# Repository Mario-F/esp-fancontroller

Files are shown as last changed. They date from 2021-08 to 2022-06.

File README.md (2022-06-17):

# Fan Controller

This is a simple project in development to provide a multi temperature sensor IoT device including a Fan Controller, the focus resides in providing a JSON HTTP interface for scrape and configure remotely.

A example schematic can be viewed [here](./schematic.pdf)

## State of the Project

The projects actual state is a working temperature fancontroller including metrics export in prometheus format.

Features:

* Control a fans speed by temp sensor of your choice
* Up to 8 temperature sensors
* Naming sensors
* Configuration is done over http
* Configuration is saved to flash memory and read on start
* Prometheus metrics export endpoint

Requriements:

* A compatible ESP8266 (i am using the  ESP-12E variant)
* DS18B20 Temparatur Sensors
* PWM Controlles FAN (4wire)

## Quickstart

Create a `src/Credentials.h` with your wifi credentials, use `src/Credentials.h.tpl`

On remote Host:

```shell
pio remote agent start
```

Connect Monitor:

```shell
pio remote device monitor -b 115200
```

Upload Filesystem:

```shell
pio remote run -t uploadfs --force-remote
```

Upload and Flash remote:

```shell
pio remote run -t upload --force-remote
```

## Configuration

Check http files at [http](./control/common.http)

## Test

To use the http calls provided by the `test/` folder you can use vscode extension `REST Client` and this config under `.vscode/settings.json`:

```json
{
  "rest-client.environmentVariables": {
    "$shared": {
        "fanControllerHost": "1.2.3.4"
    }
  }
}
```

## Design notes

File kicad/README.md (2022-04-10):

# ESP Fancontroller KiCAD

## Sources

* <https://github.com/Basirk/kicad-ESP8266>

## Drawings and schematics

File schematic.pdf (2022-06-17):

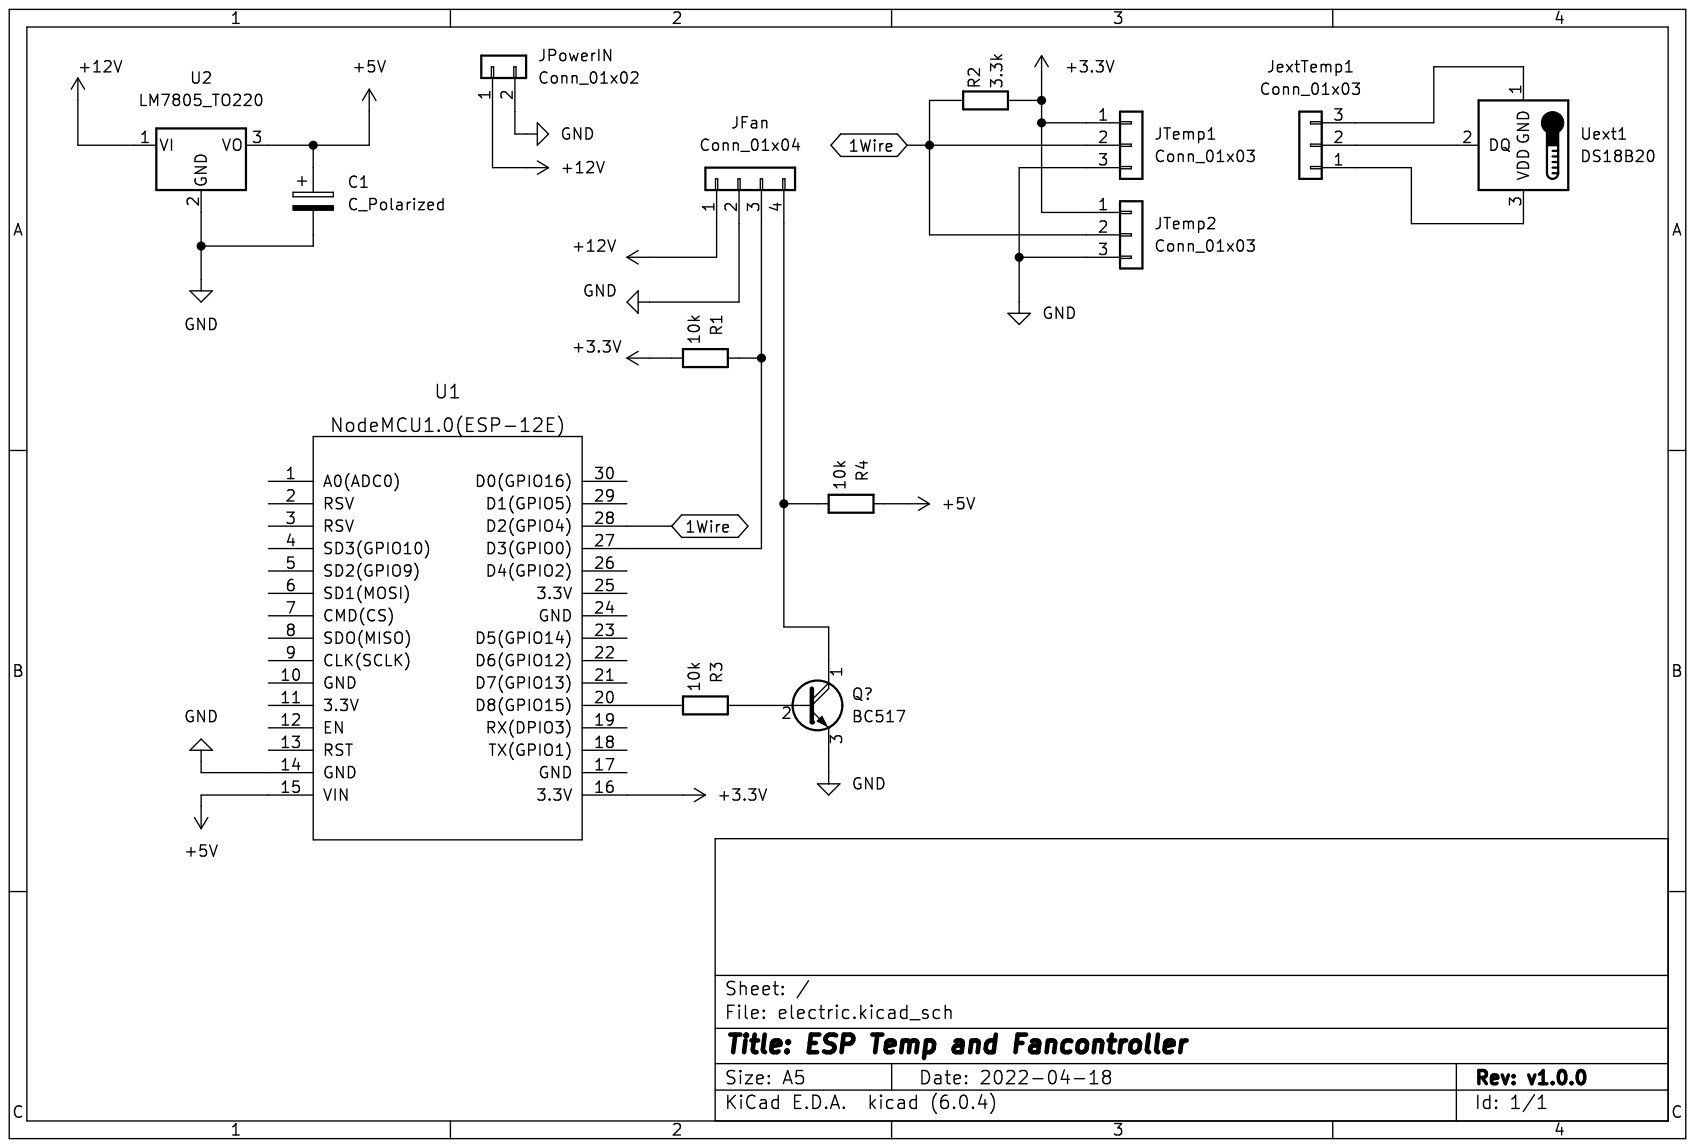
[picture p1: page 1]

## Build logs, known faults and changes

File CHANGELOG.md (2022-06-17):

## [1.0.1](https://github.com/Mario-F/esp-fancontroller/compare/v1.0.0...v1.0.1) (2022-06-17)

### Bug Fixes

* **kicad:** create updated schematic ([54e13bb](https://github.com/Mario-F/esp-fancontroller/commit/54e13bb4d6108e2599d8c90c35eac1526ac92437))

### Miscellaneous

* **kicad:** moved schematic to root level ([8c5dbdd](https://github.com/Mario-F/esp-fancontroller/commit/8c5dbddbb45d0ad8417b20ad893cc7ea08e1907a))

## 1.0.0 (2022-05-22)

### Features

* :art: added status output for wifi and chip data ([d69d1e6](https://github.com/Mario-F/esp-fancontroller/commit/d69d1e6ebad522e076c9f73d800b4b001d841ded))
* :art: moved fan functions to own controller class ([935127f](https://github.com/Mario-F/esp-fancontroller/commit/935127f24fae7acba9bc1cef40f75b0bdaf1629e))
* :rocket: progress on configuration manager ([7881e2b](https://github.com/Mario-F/esp-fancontroller/commit/7881e2be0a1dddb4992f8db848023550b6f6fbee))
* :tada: begin work on config manager ([cb3c988](https://github.com/Mario-F/esp-fancontroller/commit/cb3c9884f14cba346a7c8f8f8d19c752608c9d75))
* :white_check_mark: moved json responses to ArduinoJson ([25253c7](https://github.com/Mario-F/esp-fancontroller/commit/25253c721c5412c7e3ed9f4f043d014e6bdd787b))
* added basic metrics (prom) endpoint ([dabcb13](https://github.com/Mario-F/esp-fancontroller/commit/dabcb13324245bd66e729920437ce46721af684a))
* added endpoint to set target sensor ([8ea7231](https://github.com/Mario-F/esp-fancontroller/commit/8ea723110422440d83be419283e85b96e1561a98))
* added function to set target temp ([1a736ce](https://github.com/Mario-F/esp-fancontroller/commit/1a736ce7e426682b6dfc4689cf2a2b665bd8ac39))
* added http hint ([f69facf](https://github.com/Mario-F/esp-fancontroller/commit/f69facfd5607e1c8681c1aa31448a224536f92cd))
* added instance naming function ([1221135](https://github.com/Mario-F/esp-fancontroller/commit/1221135f71680052e9a6b277e079cc185640ef04))
* added littlefs config file ([a7b2257](https://github.com/Mario-F/esp-fancontroller/commit/a7b2257ad6ee99b8aeda5d129869e67d94719fc1))
* added MetricsManager ([a68700c](https://github.com/Mario-F/esp-fancontroller/commit/a68700c6439b438ca3a5afce557c4270e2bf40d3))
* added save and load for sensors config ([fbf5647](https://github.com/Mario-F/esp-fancontroller/commit/fbf5647b08fc36d793b7092a66f029a73809f410))
* added semantic-release ([df99ef0](https://github.com/Mario-F/esp-fancontroller/commit/df99ef027b271fb344b72f5a1609033454dce289))
* added state of development ([9d5edda](https://github.com/Mario-F/esp-fancontroller/commit/9d5edda11bf2e14335f78416197fb627b56b3011))
* **fan:** added invertable pwm ([f1688ce](https://github.com/Mario-F/esp-fancontroller/commit/f1688ce9424de60b3bc60a4ed3fafacaa6be249c))
* implement config save and default fanspeed ([dad6101](https://github.com/Mario-F/esp-fancontroller/commit/dad6101de81df73105e113d472e79db4e4fe74ba))
* implement initial fan temp regulation loop and min speed ([3d8098d](https://github.com/Mario-F/esp-fancontroller/commit/3d8098d8f54da745e140aee63d695d9587b85399))
* implement persistent sensor config names ([553c988](https://github.com/Mario-F/esp-fancontroller/commit/553c988b554092a35305f27facc4c0887cbb739a))
* **kicad:** added external esp8266 schema lib ([92a5456](https://github.com/Mario-F/esp-fancontroller/commit/92a54567cf7fb0318d002e41d7b1d69032f7264d))
* **kicad:** added fan output ([728274c](https://github.com/Mario-F/esp-fancontroller/commit/728274c60731fd144802d97b685053abbf6846fc))
* **kicad:** added folder with gitignore ([f87e762](https://github.com/Mario-F/esp-fancontroller/commit/f87e7622ff89ff17e8840cf7b009b8f1a9ee78b3))
* **kicad:** added initial schema ([83ac9ba](https://github.com/Mario-F/esp-fancontroller/commit/83ac9baa391b04ac0164315ea2143bda18726259))
* **kicad:** added inverted pwm with npn transistor ([26a1dd7](https://github.com/Mario-F/esp-fancontroller/commit/26a1dd7429f6dc3bcad4b86b78ffa68bf717dd3f))
* **kicad:** added main power connector ([cacbbb5](https://github.com/Mario-F/esp-fancontroller/commit/cacbbb5a536033471374252cbc72831ff4be9d0d))
* **kicad:** added power supply ([2212b71](https://github.com/Mario-F/esp-fancontroller/commit/2212b7137a7b87f6feb7ddc53b19c53b456bd0fa))
* **kicad:** added schmatic pdf ([f162809](https://github.com/Mario-F/esp-fancontroller/commit/f1628093d51be28d57f0f11621bcca81c8a14f14))
* **kicad:** added temp sensor circut ([7f1dbff](https://github.com/Mario-F/esp-fancontroller/commit/7f1dbffcfd1cf33a3d86ea3ccafdd922216403ff))
* **kicad:** tidy up shematic ([72aebfe](https://github.com/Mario-F/esp-fancontroller/commit/72aebfe30c0013fe253f4c1a0b26db9ac45b828e))
* **metrics:** added esp stats ([e9ab47f](https://github.com/Mario-F/esp-fancontroller/commit/e9ab47f6b84f04db90c6bfbd70e5b267e7e282d8))
* **metrics:** added local wlan ip ([800d655](https://github.com/Mario-F/esp-fancontroller/commit/800d655ff1cc420984c51e188afeb5541f20c143))
* **metrics:** added target temp for selected sensor ([236e972](https://github.com/Mario-F/esp-fancontroller/commit/236e972583302a9cf2b1a0c2e3bbf6722512e1d9))
* more intelligent fan temp step up process ([fc04ccf](https://github.com/Mario-F/esp-fancontroller/commit/fc04ccf337ee6d927e31baa42326d6ce63cb6d32))
* more prometheus metrics functions ([61698de](https://github.com/Mario-F/esp-fancontroller/commit/61698de40315ce0e4a8f76d6c17465308baedcc8))
* reduce sample rate for temp sensors ([611b1be](https://github.com/Mario-F/esp-fancontroller/commit/611b1be993f6deafc19d2a1083b04f86eb20d853))
* some cleanups and improvements ([0b6a78a](https://github.com/Mario-F/esp-fancontroller/commit/0b6a78a0fc1936c3c375fe1ce348cee30e22c3b4))
* update analogWrite to new range 0 to 255 ([175f3df](https://github.com/Mario-F/esp-fancontroller/commit/175f3dfab191ccee57bab3a42f32da30c6a343cb))
* use camel case for config json rep ([58247b5](https://github.com/Mario-F/esp-fancontroller/commit/58247b5ff6fd0d7be5a7e8624a9683cd8872fb39))
* use compiler flags for debugmode ([0f9bdea](https://github.com/Mario-F/esp-fancontroller/commit/0f9bdeae562d5de2f0a3947f590119d69439b4ef))
* verbose mode also on temp loop ([d905647](https://github.com/Mario-F/esp-fancontroller/commit/d905647e5b7df2d6193a5422f1ee1f4e414c0964))

### Bug Fixes

* :bug: onewire should be scoped at classlevel ([6e56aa8](https://github.com/Mario-F/esp-fancontroller/commit/6e56aa8d7cba68047ead7d030c22d621470209cf))
* better error handling for fan temp loop ([21f04ca](https://github.com/Mario-F/esp-fancontroller/commit/21f04ca67cc4be91ace7e8c98e554b241bc966bd))
* dont output fanspeed serial on get request ([6bda713](https://github.com/Mario-F/esp-fancontroller/commit/6bda713d13f1f55256c35361e4e17e642588f5df))
* **fan:** set pwm out pinMode before first write ([0f1e6aa](https://github.com/Mario-F/esp-fancontroller/commit/0f1e6aac7f881808fc22515c3c2667ff2f65d3a7))
* fixed log prefix red naming ([d08df0b](https://github.com/Mario-F/esp-fancontroller/commit/d08df0bfed3fa54dd35a2d925051af2386fc62dd))
* **kicad:** added pullup on pwm control because of be quiet ([981de71](https://github.com/Mario-F/esp-fancontroller/commit/981de71f2e0fed5299fa35c4e5fc0835dac6b3b7))
* **kicad:** name unnamed devices ([5a42e00](https://github.com/Mario-F/esp-fancontroller/commit/5a42e00d646533ecb777d8db2e6bd64940316bd0))
* **kicad:** named 1wire 2wire ([e9aa468](https://github.com/Mario-F/esp-fancontroller/commit/e9aa468d45ad9fc5eb63f770fa921a602983499f))
* **metrics:** same metrics must be grouped together ([d09b2af](https://github.com/Mario-F/esp-fancontroller/commit/d09b2af51830947a46fd3a2c87188bcbf86301f2))
* new analogWrite range ([e8b7ae0](https://github.com/Mario-F/esp-fancontroller/commit/e8b7ae0d83d044cb6ae39f36f4ba91f76c160dde))
* removed config experiments ([ca8d4a6](https://github.com/Mario-F/esp-fancontroller/commit/ca8d4a61507584ef3b6bec8f546107f102cf05ec))
* removed npm token ([1d278bf](https://github.com/Mario-F/esp-fancontroller/commit/1d278bfd86c962d916e0bf549578e191fc670725))
* removed red information ([83fc22a](https://github.com/Mario-F/esp-fancontroller/commit/83fc22a5f7d8f52d4305196af53a6f04772fbc9e))
* set fan 100 on startup ([58582a7](https://github.com/Mario-F/esp-fancontroller/commit/58582a7da4e4741b02118bc7189db2b4cb57d073))

### Performance Improvements

* added stepdown skip logic ([573da23](https://github.com/Mario-F/esp-fancontroller/commit/573da23bdc4ef04f71551cb3e945672d82c49853))
* added upskip logic to temp loop ([4167d8c](https://github.com/Mario-F/esp-fancontroller/commit/4167d8c7f0df4405432836d8e732e8a1357903fd))
* decrease temploop executions time ([bc13904](https://github.com/Mario-F/esp-fancontroller/commit/bc13904521261b8f1816e53be4dcb81c1834cb8a))
* **ftloop:** tune loop parameters ([cc848d7](https://github.com/Mario-F/esp-fancontroller/commit/cc848d74841e2cc2d2832cb6d07dde3b384d7da2))
* half the fan/temp control loop reaction time ([f379fb4](https://github.com/Mario-F/esp-fancontroller/commit/f379fb4bdade02c73c010f61dc7ad72154fd4579))
* increase temploop skip steps ([b28e2e2](https://github.com/Mario-F/esp-fancontroller/commit/b28e2e26d1c6aba5d49191fd84d1656459b995bf))
* increase temploop stepup ([398f4f9](https://github.com/Mario-F/esp-fancontroller/commit/398f4f99a2e885a4dad41391c710591f2238b3ec))
* **kicad:** 10k for pwm drive is even better ([c96418f](https://github.com/Mario-F/esp-fancontroller/commit/c96418fe368e2168c504c7a671e7fd5139427dff))
* **kicad:** use 5k resistor for pwm drive ([e434b6e](https://github.com/Mario-F/esp-fancontroller/commit/e434b6e438437f11f2603b056cf54fcf6df095ef))
* **metrics:** increase coutns a bit more ([a86a08c](https://github.com/Mario-F/esp-fancontroller/commit/a86a08c53f9c541a6502b1b4efb281b71589ffff))
* **metrics:** increase max metrics and local labels ([3f338b4](https://github.com/Mario-F/esp-fancontroller/commit/3f338b47956a25fc4fd0f9a492159fc6ab32e953))
* **metrics:** refined metric counts a bit more ([bfa97f7](https://github.com/Mario-F/esp-fancontroller/commit/bfa97f77fad216ddb7b7062867010b00565ae08d))
* tuning on fan temp loop ([8af41a0](https://github.com/Mario-F/esp-fancontroller/commit/8af41a02293addf9e3793e6ae17d0f5d5b3bacc3))

### Malformed Commits

* Merge pull request #1 from Mario-F/dev ([b6de396](https://github.com/Mario-F/esp-fancontroller/commit/b6de396a8fa3e6eefd36493818517a7a5db2e971)), closes [#1](https://github.com/Mario-F/esp-fancontroller/issues/1)
* first commit ([b9b03fb](https://github.com/Mario-F/esp-fancontroller/commit/b9b03fb065cffcc9b10f9b39b48116efde4b4a15))

### Miscellaneous

* added http endpoints to docs ([7219022](https://github.com/Mario-F/esp-fancontroller/commit/72190224dd2d3a3f97371eb4605cf23a8dfabfb9))
* added inline todo ([aa65e2c](https://github.com/Mario-F/esp-fancontroller/commit/aa65e2c744604454cef01be23bca90033cf55259))
* added project state to readme ([2589699](https://github.com/Mario-F/esp-fancontroller/commit/25896990bccbe5ba9715cdb9f8fb9eb24c5dc5f3))
* added release file ([e5f0ce8](https://github.com/Mario-F/esp-fancontroller/commit/e5f0ce801c74eb71eece4cae0100ce341395aaa4))
* added release workflow ([5b5946f](https://github.com/Mario-F/esp-fancontroller/commit/5b5946fe9a20f421423898cdd153957a676c4b81))
* added todo ([422fd46](https://github.com/Mario-F/esp-fancontroller/commit/422fd461d4f93397416edbdf6056ae8394693b0e))
* encapsulate link ([a562409](https://github.com/Mario-F/esp-fancontroller/commit/a562409d1e9a2e01ee5ea788884a28e16fdaec54))
* fixed typo ([b079676](https://github.com/Mario-F/esp-fancontroller/commit/b07967676a4c32589cbe83d6484051b36c4836c7))
* fixed typo in http test ([f38e26c](https://github.com/Mario-F/esp-fancontroller/commit/f38e26cb24b00a106287dbc378ca5f8f9ce4458f))
* improve readme ([23e2910](https://github.com/Mario-F/esp-fancontroller/commit/23e2910bf19375d5f55b045ba9354fb75e2ec780))
* **kicad:** added schematic link to README ([9d0f55b](https://github.com/Mario-F/esp-fancontroller/commit/9d0f55bf6c6592fdc2a16da5a235d2c676b18b29))
* make clear temp sensor addr/name to uid ([4f38324](https://github.com/Mario-F/esp-fancontroller/commit/4f383243a86daf0a052ce7ca790864abf845e347))
* remove npm from release file ([1c8754c](https://github.com/Mario-F/esp-fancontroller/commit/1c8754c9388a3e16d8444603b448ddab5af91e29))
* start test with http request files ([1174c11](https://github.com/Mario-F/esp-fancontroller/commit/1174c112fc4abf43c0d3594499cad9f7885e5b8c))

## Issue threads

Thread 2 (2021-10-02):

PWM Timing Problems

Mario-F, 2021-10-02:
The PWM of the ESP8266 is done in software and must run significant higher than the specs allow, a problem that comes up is at some levels of pwm the 1wire communication is affected.

The actual workaround is an active backoff on error routine, this means on 1wire error only a counter will increase till the next valid result from the sensor reading.

Mario-F, 2022-04-18:
The problem seems to be fixed, maybe because of updated lib uses smaller pwm range (analogWriteRange = 255) by default

Closed 2022-04-18.

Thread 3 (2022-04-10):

Provide schematics

Mario-F, 2022-04-10:
The Repository should have some schematics for wiring as an example

Mario-F, 2022-04-18:
done in https://github.com/Mario-F/esp-fancontroller/tree/main/kicad

Closed 2022-04-18.

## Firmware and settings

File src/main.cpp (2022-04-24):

/*
 * Fancontroller MAIN File
 */
#include <ArduinoJson.h>
#include <Arduino.h>
#include <ESP8266WebServer.h>
#include <uri/UriBraces.h>
#include <uri/UriRegex.h>
#include "Credentials.h"
#include "ConfigManager/ConfigManager.h"
#include "ControllerTemp/ControllerTemp.h"
#include "ControllerFan/ControllerFan.h"
#include "Metrics/Metrics.h"

/* Set pin usage */
#define ONE_WIRE_BUS D2
#define FAN_RPM_INPUT D3
#define FAN_PWM_OUTPUT D8
#define FAN_PWM_INVERT true

/* Define Objects */
ESP8266WebServer server(80);
ControllerTemp temps(ONE_WIRE_BUS);
ControllerFan fana(FAN_RPM_INPUT, FAN_PWM_OUTPUT, FAN_PWM_INVERT);
boolean loopFanTempVerbose = false;

/* Define and Setup W-Lan */
const char* ssid = WIFI_SSID;  // Enter SSID here
const char* password = WIFI_PW;  //Enter Password here


/*
Webserver handles
*/
void handle_verbose() {
  boolean newVerbose = false;
  String verboseInput = server.pathArg(0);
  Serial.print("Change verbose mode with input: "); Serial.println(verboseInput);
  if(verboseInput == "yes") newVerbose = true;
  fana.setVerbose(newVerbose);
  temps.setVerbose(newVerbose);
  ConfigManager::setVerbose(newVerbose);
  loopFanTempVerbose = true;
  server.send(200, "text/plain", "New verbose status is: '" + String(newVerbose) + "'");
}

void handle_Status() {
  DynamicJsonDocument jsonResponse(512);

  DynamicJsonDocument instanceData(128);
  instanceData["name"] = ConfigManager::getConfig().instanceName;
  instanceData["targetTemp"] = ConfigManager::getConfig().targetTemp;
  instanceData["targetSensor"] = ConfigManager::getConfig().targetSensor;
  jsonResponse["instance"] = instanceData;

  DynamicJsonDocument wifiData(128);
  wifiData["ssid"] = WiFi.SSID();
  wifiData["ip"] = WiFi.localIP().toString();
  wifiData["gateway"] = WiFi.gatewayIP().toString();
  wifiData["netmask"] = WiFi.subnetMask().toString();
  wifiData["signal"] = WiFi.RSSI();
  jsonResponse["wifi"] = wifiData;

  DynamicJsonDocument chipData(128);
  chipData["chipId"] = ESP.getChipId();
  chipData["flashChipId"] = ESP.getFlashChipId();
  chipData["flashChipSize"] = ESP.getFlashChipSize();
  chipData["flashChipRealSize"] = ESP.getFlashChipRealSize();
  chipData["freeHeap"] = ESP.getFreeHeap();
  jsonResponse["chip"] = chipData;

  String buf;
  serializeJson(jsonResponse, buf);
  server.send(200, "application/json", buf);
}

void handle_Sensors() {
  DynamicJsonDocument jsonResponse(1024);
  for (int i = 0; i < MAX_SENSORS; i++) {
    SensorConfig sens = ConfigManager::getConfig().sensors[i];
    DynamicJsonDocument jsonSensor(256);
    jsonSensor["slot"] = i;
    jsonSensor["sensorUID"] = sens.sensorUID;
    jsonSensor["sensorName"] = sens.sensorName;
    jsonResponse.add(jsonSensor);
  }
  String buf;
  serializeJson(jsonResponse, buf);
  server.send(200, "application/json", buf);
}

void handle_SensorsUpdate() {
  String sensorUID = server.pathArg(0);
  String sensorName = server.pathArg(1);
  String errorMessage = "";
  // Check if sensor exists
  ControllerSensor retSensor;
  if (!temps.getSensorByUID(sensorUID, &retSensor)) {
    server.send(404, "text/plain", "Sensor for update not found");
    return;
  }
  if (!ConfigManager::setSensorName(sensorUID, sensorName, &errorMessage)) {
    Serial.print("Error: "); Serial.println(errorMessage);
    server.send(507, "text/plain", errorMessage);
    return;
  }
  server.send(200, "text/plain");
}

void handle_Temps() {
  DynamicJsonDocument jsonResponse(1024);
  int sensorCount = temps.getDeviceCount();
  for (int i = 0; i < sensorCount; i++) {
    ControllerSensor sensor = temps.getSensor(i);
    DynamicJsonDocument jsonSensor(256);
    jsonSensor["type"] = "ds18b20";
    jsonSensor["uid"] = sensor.getUID();
    if (sensor.getName() != "") {
      jsonSensor["name"] = sensor.getName();
    }
    jsonSensor["temp"] = sensor.getTemp();
    jsonSensor["errors"] = sensor.getErrorCount();
    jsonResponse.add(jsonSensor);
  }
  String buf;
  serializeJson(jsonResponse, buf);
  server.send(200, "application/json", buf);
}

void handle_Speeds() {
  DynamicJsonDocument jsonResponse(512);
  DynamicJsonDocument singleFan(256);
  singleFan["type"] = "fan";
  singleFan["rpm"] = fana.getRPM();
  singleFan["speed"] = fana.getSpeed();
  singleFan["defaultSpeed"] = ConfigManager::getConfig().defaultSpeed;
  singleFan["minimumSpeed"] = ConfigManager::getConfig().minimumSpeed;
  jsonResponse.add(singleFan);
  String buf;
  serializeJson(jsonResponse, buf);
  server.send(200, "application/json", buf);
}

void handle_Metrics() {
  MainConfig mConfig = ConfigManager::getConfig();

  MetricsManager::resetGlobalLabels();
  MetricsManager::addGlobalLabel("instance", ConfigManager::getConfig().instanceName);
  MetricsManager::resetMetrics();

  Metric *fInfo = MetricsManager::createMetric("fancontroller_info", "gauge", "A metric with constant 1 to create labels with information about this instance");
  fInfo->value = 1;

  Metric *fEspInfo = MetricsManager::createMetric("fancontroller_esp_info", "gauge", "A metric with constant 1 with infos about the ESP");
  fEspInfo->value = 1;
  MetricsManager::addMetricLabel(fEspInfo, "chip_id", (String)ESP.getChipId());
  MetricsManager::addMetricLabel(fEspInfo, "flash_chip_id", (String)ESP.getFlashChipId());
  
  Metric *fEspFreeHeap = MetricsManager::createMetric("fancontroller_esp_free_heap", "gauge", "Show the actual free heap of the ESP");
  fEspFreeHeap->value = ESP.getFreeHeap();

  Metric *fWlan = MetricsManager::createMetric("fancontroller_wlan_info", "gauge", "A metric with constant 1 to create labels with wlan information");
  fWlan->value = 1;
  MetricsManager::addMetricLabel(fWlan, "ssid", WiFi.SSID());
  MetricsManager::addMetricLabel(fWlan, "ip", WiFi.localIP().toString());

  Metric *fWlanRssi = MetricsManager::createMetric("fancontroller_wlan_signal", "gauge", "The wlan signal strength for the connected network");
  fWlanRssi->value = (float)WiFi.RSSI();

  Metric *fRPM = MetricsManager::createMetric("fancontroller_fan_rpm", "gauge", "The fans actual RPM value read by yellow signal");
  fRPM->value = fana.getRPM();

  Metric *fSpeed = MetricsManager::createMetric("fancontroller_fan_speed", "gauge", "The desired speed in percent");
  fSpeed->value = fana.getSpeed();

  int sensorCount = temps.getDeviceCount();
  for (int i = 0; i < sensorCount; i++) {
    ControllerSensor sensor = temps.getSensor(i);
    
    Metric *fTemp = MetricsManager::createMetric("fancontroller_sensor_temp", "gauge", "The actual temp of a sensor");
    MetricsManager::addMetricLabel(fTemp, "uid", sensor.getUID());
    MetricsManager::addMetricLabel(fTemp, "name", sensor.getName());
    fTemp->value = sensor.getTemp();

    // if sensor is target create metric for target temp
    if (mConfig.targetSensor == sensor.getUID()) {
      Metric *fTargetTemp = MetricsManager::createMetric("fancontroller_sensor_target_temp", "gauge", "The target temp fan control is set to");
      MetricsManager::addMetricLabel(fTargetTemp, "uid", sensor.getUID());
      MetricsManager::addMetricLabel(fTargetTemp, "name", sensor.getName());
      fTargetTemp->value = mConfig.targetTemp;
    }

    Metric *fErrorsValue = MetricsManager::createMetric("fancontroller_sensor_errors", "counter", "Errors in a row since last succesfull result");
    MetricsManager::addMetricLabel(fErrorsValue, "uid", sensor.getUID());
    MetricsManager::addMetricLabel(fErrorsValue, "name", sensor.getName());
    fErrorsValue->value = sensor.getErrorCount();
  }

  String response = MetricsManager::getMetrics();
  server.send(200, "application/json", response);
}

void handle_NotFound(){
  server.send(404, "text/plain", "Not found");
}


/*
Handle the fan/temp regulation
*/
int loopFanTempLastExecute = millis();
int loopFanTempLoopTimer = 20000;
int loopFanTempAllowErrors = 20;
int loopFanTempUpStepsMax = 15;
int loopFanTempDownSteps = 1;
int loopFanTempUpStepsSkip = 0;
int loopFanTempDownStepsSkip = 0;
float loopFanTempLastTemp = 0;
void loopFanTemp() {
  // Check for execution time reached
  int timePassed = (millis() - loopFanTempLastExecute);
  if (timePassed > loopFanTempLoopTimer) {
    MainConfig mConfig = ConfigManager::getConfig();
    ControllerSensor retSensor;
    if (!temps.getSensorByUID(mConfig.targetSensor, &retSensor)) {
      if (loopFanTempVerbose) {
        Serial.println("(LoopFanTemp) No target sensor is set, aborting.");
      }
      loopFanTempLastExecute = millis();
      return;
    }

    // Set default to step down and validate different values to step up
    boolean stepUpNeeded = false;
    if (retSensor.getErrorCount() > loopFanTempAllowErrors) {
      stepUpNeeded = true;
    }
    float readTemp = retSensor.getTemp();
    if (readTemp > mConfig.targetTemp) {
      stepUpNeeded = true;
    }

    // Set new fanspeed
    int actFanSpeed = fana.getSpeed();
    if (stepUpNeeded) {
      if (loopFanTempUpStepsSkip <= 10 && readTemp < loopFanTempLastTemp) {
        loopFanTempUpStepsSkip++;
        if (loopFanTempVerbose) {
          Serial.println("(LoopFanTemp) Temp is decreasing, dont step up.");
        }
      } else {
        loopFanTempUpStepsSkip = 0;
        int stepUpCalculated = constrain((retSensor.getTemp() - mConfig.targetTemp) * 2, 1, loopFanTempUpStepsMax);
        fana.setSpeed(actFanSpeed + stepUpCalculated);
        if (loopFanTempVerbose) {
          Serial.print("(LoopFanTemp) Execute StepUP for fana: "); Serial.println(stepUpCalculated);
        }
      }
    } else {
      if (loopFanTempDownStepsSkip <= 10 && readTemp > loopFanTempLastTemp) {
        loopFanTempDownStepsSkip++;
        if (loopFanTempVerbose) {
          Serial.println("(LoopFanTemp) Temp is increasing, dont step down.");
        }
      } else {
        loopFanTempDownStepsSkip = 0;
        Serial.println("(LoopFanTemp) Execute StepDOWN for fana.");
        fana.setSpeed(actFanSpeed - loopFanTempDownSteps);
      }
    }
    loopFanTempLastTemp = readTemp;
    loopFanTempLastExecute = millis();
  }
}


/*
Main components
*/
void setup() {
  /* Try to counter some boot problems */
  __asm__("nop\n\t"); delay(1000); __asm__("nop\n\t");
  Serial.begin(115200); Serial.println(); Serial.println("Start setup!");

  /* Setup debugmode stuff */
  #ifdef DEBUGMODE
  fana.setVerbose(true);
  temps.setVerbose(true);
  ConfigManager::setVerbose(true);
  loopFanTempVerbose = true;
  #endif

  /* Init the config from file */
  ConfigManager::initConfig("/config.json");

  /* Connect to wifi */
  Serial.print("Connecting to WIFI "); Serial.println(ssid);
  WiFi.begin(ssid, password);
  while (WiFi.status() != WL_CONNECTED) {
    delay(1000);
    Serial.print(".");
  }
  Serial.println(" succesfully connected!");
  Serial.print("IP: "); Serial.println(WiFi.localIP());

  /* Setup temp sensors */
  temps.setSampleRate(5765);
  temps.setSampleRateAdvance(1372);
  temps.initSensors(true);

  /* Set fan to default speed */
  fana.setSpeed(ConfigManager::getConfig().defaultSpeed);

  /* Setup Webserver handling */
  server.on(UriBraces("/verbose/{}"), handle_verbose);
  server.on("/status", handle_Status);
  server.on("/temps", handle_Temps);
  server.on("/fans", handle_Speeds);
  server.on(UriBraces("/speed/default/{}"), []() {
    String newspeedS = server.pathArg(0);
    int newspeed = (int)newspeedS.toInt();
    ConfigManager::setDefaultSpeed(newspeed);
    server.send(200, "text/plain", "DEFAULT FAN SPEED UPDATED: '" + newspeedS + "'");
  });
  server.on(UriBraces("/speed/minimum/{}"), []() {
    String newspeedS = server.pathArg(0);
    int newspeed = (int)newspeedS.toInt();
    // Set this also as new default speed
    ConfigManager::setDefaultSpeed(newspeed);
    server.send(200, "text/plain", "MINIMUM FAN SPEED UPDATED: '" + newspeedS + "'");
  });
  server.on(UriBraces("/name/{}"), []() {
    String newName = server.pathArg(0);
    ConfigManager::setInstanceName(newName);
    Serial.print("New instance Name: "); Serial.println(newName);
    server.send(200, "text/plain");
  });
  server.on(UriBraces("/target/temp/{}"), []() {
    String targetTemp = server.pathArg(0);
    int targetTempInt = targetTemp.toInt();
    ConfigManager::setTargetTemp(targetTempInt);
    server.send(200, "text/plain");
  });
  server.on(UriBraces("/target/sensor/{}"), []() {
    String targetSensor = server.pathArg(0);
    // Check if sensor exists
    ControllerSensor retSensor;
    if (!temps.getSensorByUID(targetSensor, &retSensor)) {
      server.send(404, "text/plain", "Sensor for update not found");
      return;
    }
    ConfigManager::setTargetSensor(targetSensor);
    server.send(200, "text/plain");
  });
  server.on("/sensors", handle_Sensors);
  server.on(UriBraces("/sensors/{}/{}"), handle_SensorsUpdate);
  server.on("/metrics", handle_Metrics);
  server.onNotFound(handle_NotFound);
  server.begin();
  Serial.println("HTTP server started");
}

void loop() {
  server.handleClient();
  fana.loop();
  temps.loop();
  loopFanTemp();
}

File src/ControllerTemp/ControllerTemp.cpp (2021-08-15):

// Abstract DallasTempSensor functions

#include "ControllerTemp.h"
#include <OneWire.h>
#include "ConfigManager/ConfigManager.h"

/*
 * Manage Dalls Temp activities
 */
ControllerTemp::ControllerTemp() {};
ControllerTemp::ControllerTemp(uint8_t _pin) {
  // Init DallasTemp
  pin = _pin;
  myWire = OneWire(_pin);

  // defaults
  lastTempPull = millis();
  verbose = false;
  deviceCount = 0;
  sampleRate = 2750;
  sampleRateAdvance = 850;
  requestSend = false;
}

void ControllerTemp::setVerbose(bool _flag) {
  verbose = _flag;
}

void ControllerTemp::setSampleRate(int _sampleRate) {
  sampleRate = _sampleRate;
}

void ControllerTemp::setSampleRateAdvance(int _sampleRateAdvance) {
  sampleRateAdvance = _sampleRateAdvance;
}

void ControllerTemp::initSensors(boolean waitForSensors) {
  dTemp = DallasTemperature(&myWire);

  dTemp.begin();
  deviceCount = dTemp.getDeviceCount();
  while(waitForSensors && deviceCount <= 0) {
    // TODO: Can cause infinite loops, implement some sort auf error status for this case
    Serial.println(LOG_PREFIX_CT"(init) No temp sensors found try again after 1sec");
    delay(1000);
    deviceCount = dTemp.getDeviceCount();
  }
  if(verbose) {
    Serial.print(LOG_PREFIX_CT"(init) Found "); Serial.print(deviceCount); Serial.println(" Devices.");
  }
  dTemp.setWaitForConversion(true);
  dTemp.requestTemperatures();
  for (int i = 0; i < deviceCount; i++) {
    DeviceAddress deviceAddress;
    dTemp.getAddress(deviceAddress, i);
    float temp = dTemp.getTempC(deviceAddress);
      if(verbose) {
        Serial.print(LOG_PREFIX_CT"(Loop-Conversion) Temp ");
        Serial.print(temp);
        Serial.print(" from Device (directDeviceAddress) ");
        for(uint8_t i = 0; i < 8; i++) Serial.print(String(deviceAddress[i], HEX));
        Serial.println();
      }
    sensors[i] = ControllerSensor(deviceAddress);
    if(verbose) {
      Serial.print(LOG_PREFIX_CT"(init) Got sensor "); Serial.println(sensors[i].getUID());
    }
  }
  dTemp.setWaitForConversion(false);
  dTemp.requestTemperatures();
}

void ControllerTemp::resetLoop() {
  requestSend = false;
  lastTempPull = millis();
}

void ControllerTemp::loop() {
  int timePassed = (millis() - lastTempPull);

  // Check if temp conversion request was already send and time is right
  if ( !requestSend &&  timePassed >= ( sampleRate - sampleRateAdvance ) ) {
    if(verbose) {
      Serial.print(LOG_PREFIX_CT"(Loop-Request) Time passed "); Serial.print(timePassed); Serial.println("ms");
    }
    requestSend = true;
    dTemp.requestTemperatures();
  }

  // Check if sample rate reached and request temp and reset loop
  if (timePassed >= sampleRate ) {
    if(verbose) {
      Serial.print(LOG_PREFIX_CT"(Loop-Conversion) Time passed "); Serial.print(timePassed); Serial.println("ms");
    }
    for (int i = 0; i < deviceCount; i++) {
      DeviceAddress dadd;
      sensors[i].getAddress(dadd);
      float temp = dTemp.getTempC(dadd);
      if(verbose) {
        Serial.print(LOG_PREFIX_CT"(Loop-Conversion) Temp ");
        Serial.print(temp);
        Serial.print(" from Device (directDeviceAddress) ");
        for(uint8_t i = 0; i < 8; i++) Serial.print(String(dadd[i], HEX));
        Serial.println();
      }
      if (temp != DEVICE_DISCONNECTED_C) {
        sensors[i].setTemp(temp);
      } else {
        sensors[i].setError();
      }
      if(verbose) {
        Serial.print(LOG_PREFIX_CT"(Loop-Conversion) Convert Sensor ");
        Serial.print(sensors[i].getUID() + ", Temp: ");
        Serial.print(sensors[i].getTemp());
        Serial.print(" celsius, Errors: ");
        Serial.println(sensors[i].getErrorCount());
      }
    }

    // Reset loop
    resetLoop();
  }
}

int ControllerTemp::getDeviceCount() {
  return deviceCount;
}

ControllerSensor ControllerTemp::getSensor(int _sensorIndex) {
  return sensors[_sensorIndex];
}

boolean ControllerTemp::getSensorByUID(String sensorUID, ControllerSensor *foundSensor) {
  int sensorCount = this->getDeviceCount();
  for (int i = 0; i < sensorCount; i++) {
    ControllerSensor sensor = this->getSensor(i);
    if (sensor.getUID() == sensorUID) {
      *foundSensor = sensor;
      return true;
    }
  }
  return false;
}


/*
 * Hold state of a single sensor
 */
ControllerSensor::ControllerSensor() {};
ControllerSensor::ControllerSensor(DeviceAddress _deviceAddress) {
  for(uint8_t i = 0; i < 8; i++) {
    deviceAddress[i] = _deviceAddress[i];
  }
  deviceAddressString = convertAddress(deviceAddress);
  temp = DEVICE_DISCONNECTED_C;
  errors = 0;
}

String ControllerSensor::getUID() {
  return deviceAddressString;
}

String ControllerSensor::getName() {
  return ConfigManager::getSensorByUID(this->getUID()).sensorName;
}

void ControllerSensor::getAddress(DeviceAddress _deviceAddress) {
  for(uint8_t i = 0; i < 8; i++) {
    _deviceAddress[i] = deviceAddress[i];
  }
}

void ControllerSensor::setTemp(float _temp) {
  // Also reset errors because setTemp is only for valid values
  temp = _temp;
  errors = 0;
}

float ControllerSensor::getTemp() {
  return temp;
}

void ControllerSensor::setError() {
  errors++;
}

int ControllerSensor::getErrorCount() {
  return errors;
}

String ControllerSensor::convertAddress(DeviceAddress _deviceAddress) {
  String result = "";
  for (uint8_t i = 0; i < 8; i++)
  {
    result += String(_deviceAddress[i], HEX);
  }
  return result;
}

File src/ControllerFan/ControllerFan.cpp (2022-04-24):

// Abstract PWM RPM Counter functions for Fancontrol

#include "ControllerFan.h"
#include "ConfigManager/ConfigManager.h"

ControllerFan* ControllerFan::cfInstance = 0;

ControllerFan::ControllerFan() {};
ControllerFan::ControllerFan(uint8_t _pinRPM, uint8_t _pinPWM, bool _invertedPWM) {
  pinRPM = _pinRPM;
  pinPWM = _pinPWM;
  invertedPWM = _invertedPWM;

  fanRPMCounter = 0;
  fanActRPM = 0;
  fanSetSpeed = 0;
  
  pinMode(pinPWM, OUTPUT);
  analogWriteFreq(22000);
  setSpeed(100);
  
  cfInstance = this;
  attachInterrupt(digitalPinToInterrupt(pinRPM), ControllerFan::incrISR, RISING);
};

void ControllerFan::setVerbose(bool _flag) {
  verbose = _flag;
}

void ControllerFan::setSpeed(int newSpeed) {
  int minSpeed = ConfigManager::getConfig().minimumSpeed;
  fanSetSpeed = constrain(newSpeed, minSpeed, 100);
  if(verbose) {
    Serial.print(LOG_PREFIX_CF"(setSpeed) Set new Speed ");
    Serial.println(fanSetSpeed);
  }
  if(invertedPWM) {
    int invertedSetSpeed = abs(fanSetSpeed - 100);
    if(verbose) {
      Serial.print(LOG_PREFIX_CF"(setSpeed) PWM is inverted, final value is ");
      Serial.println(invertedSetSpeed);
    }
    analogWrite(pinPWM, invertedSetSpeed * 2.55);
  } else {
    analogWrite(pinPWM, fanSetSpeed * 2.55);
  }
};

int ControllerFan::getSpeed() {
  return fanSetSpeed;
};

int ControllerFan::getRPM() {
  return fanActRPM;
};

void ControllerFan::loop() {
  int timePassed = (millis() - fanRPMTimer);
  if(timePassed > 2000) {
    // Set Fanspeed
    fanActRPM = (fanRPMCounter * 30 / 2);

    if(verbose) {
      Serial.print(LOG_PREFIX_CF"(loop) FanSpeed - Time passed ");
      Serial.print(timePassed);
      Serial.print("ms, with Fanspeed: ");
      Serial.print(fanActRPM);
      Serial.println(" rpm");
    }

    // Reset loop
    fanRPMTimer = millis();
    fanRPMCounter = 0;
  }
};

ICACHE_RAM_ATTR void ControllerFan::incrISR() {
  if (cfInstance != 0) {
    cfInstance->fanRPMCounter++;
  }
};

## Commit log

2021-05-03 fix: :bug: onewire should be scoped at classlevel
    [ControllerTemp.cpp]
2021-05-04 feat: :art: moved fan functions to own controller class
2021-05-04 fix: removed config experiments
    [main.cpp]
2021-05-04 fix: dont output fanspeed serial on get request
    [main.cpp]
2021-05-04 feat: reduce sample rate for temp sensors
2021-05-10 feat: :white_check_mark: moved json responses to ArduinoJson
2021-05-10 refactor: make clear temp sensor addr/name to uid
2021-05-29 fix: removed red information
    [main.cpp]
2021-05-29 fix: fixed log prefix red naming
    [ConfigManager.cpp, ControllerFan.cpp, ControllerTemp.cpp]
2021-06-04 feat: use camel case for config json rep
2021-06-06 feat: added save and load for sensors config
2021-06-06 feat: implement persistent sensor config names
2021-06-06 feat: added endpoint to set target sensor
2021-06-06 feat: implement initial fan temp regulation loop and min speed
2021-06-06 fix: better error handling for fan temp loop
    [main.cpp]
2021-06-07 perf: tuning on fan temp loop
2021-06-07 feat: more intelligent fan temp step up process
2021-08-15 fix: set fan 100 on startup
    [main.cpp]
2022-04-10 feat(kicad): added folder with gitignore
2022-04-10 feat(kicad): added initial schema
    [electric.kicad_pcb, electric.kicad_sch]
2022-04-10 feat(kicad): added external esp8266 schema lib
    [electric.kicad_pcb, electric.kicad_sch]
2022-04-16 feat(kicad): added power supply
    [electric.kicad_sch]
2022-04-16 feat(kicad): added main power connector
    [electric.kicad_sch]
2022-04-17 feat(kicad): added fan output
    [electric.kicad_sch]
2022-04-17 fix(kicad): name unnamed devices
    [electric.kicad_sch]
2022-04-17 feat(kicad): added temp sensor circut
    [electric.kicad_sch]
2022-04-18 feat(kicad): tidy up shematic
    [electric.kicad_sch]
2022-04-18 feat(kicad): added schmatic pdf
2022-04-18 docs(kicad): added schematic link to README
2022-04-18 fix: new analogWrite range
    [ControllerFan.cpp]
2022-04-18 perf: half the fan/temp control loop reaction time
2022-04-19 fix(kicad): named 1wire 2wire
    [electric.kicad_sch]
2022-04-20 feat(metrics): added target temp for selected sensor
2022-04-20 perf: added stepdown skip logic
    [main.cpp]
2022-04-20 perf: increase temploop skip steps
    [main.cpp]
2022-04-24 fix(fan): set pwm out pinMode before first write
    [ControllerFan.cpp, main.cpp]
2022-04-24 feat(fan): added invertable pwm
2022-04-24 feat(kicad): added inverted pwm with npn transistor
    [electric.kicad_sch]
2022-04-24 perf(kicad): use 5k resistor for pwm drive
    [electric.kicad_sch]
2022-04-24 perf(kicad): 10k for pwm drive is even better
    [electric.kicad_sch]
2022-05-05 fix(kicad): added pullup on pwm control because of be quiet
    [electric.kicad_sch]
2022-05-22 chore(release): 1.0.0
    ## 1.0.0 (2022-05-22)
    ### Features
    * :art: added status output for wifi and chip data ([d69d1e6](https://github.com/Mario-F/esp-fancontroller/commit/d69d1e6ebad522e076c9f73d800b4b001d841ded))
    * :art: moved fan functions to own controller class ([935127f](https://github.com/Mario-F/esp-fancontroller/commit/935127f24fae7acba9bc1cef40f75b0bdaf1629e))
    * :rocket: progress on configuration manager ([7881e2b](https://github.com/Mario-F/esp-fancontroller/commit/7881e2be0a1dddb4992f8db848023550b6f6fbee))
    * :tada: begin work on config manager ([cb3c988](https://github.com/Mario-F/esp-fancontroller/commit/cb3c9884f14cba346a7c8f8f8d19c752608c9d75))
    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
2022-06-17 fix(kicad): create updated schematic
2022-06-17 docs(kicad): moved schematic to root level
2022-06-17 chore(release): 1.0.1
    ## [1.0.1](https://github.com/Mario-F/esp-fancontroller/compare/v1.0.0...v1.0.1) (2022-06-17)
    ### Bug Fixes
    * **kicad:** create updated schematic ([54e13bb](https://github.com/Mario-F/esp-fancontroller/commit/54e13bb4d6108e2599d8c90c35eac1526ac92437))
    ### Miscellaneous
    * **kicad:** moved schematic to root level ([8c5dbdd](https://github.com/Mario-F/esp-fancontroller/commit/8c5dbddbb45d0ad8417b20ad893cc7ea08e1907a))
2023-08-06 feat(kicad): update to version 7
    [electric.kicad_pcb, electric.kicad_sch]
